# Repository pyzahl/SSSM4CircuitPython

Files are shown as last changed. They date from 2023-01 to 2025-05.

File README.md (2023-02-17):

# SSSM4CircuitPython
Solar Scintillation Seeing Monitor (SSSM) for CircuitPython

A renewed verion of a SSSM for CircuitPython on a ESP32-S2 or -S3-TFT.

Project based on hardware described here
https://www.blackwaterskies.co.uk/2017/06/diy-solar-scintillation-seeing-monitor-sssm/
or originally here:
https://vdocuments.mx/an-inexpensive-solar-scintillation-seeing-monitor-circuit-an-inexpensive.html

Let me copy the intro to SSSM:

A guide to building an inexpensive Solar Scintillation Seeing Monitor. The SSSM is a handy device which monitors the atmospheric seeing conditions during solar imaging. This SSSM can be built for a fraction of the cost of commercially available devices. You can use the SSSM to monitor seeing conditions through the day, or even to control your camera to capture images during the best seeing conditions.

Background:
The original design for the SSSM was published by E. J. Seykora at the Department of Physics, East Carolina University.

Read also how to integrate with Firecapture:
http://www.firecapture.de/
http://www.joachim-stehle.de/downloads/SSSMon/SSSMonPluginManual.pdf

Adapted schematics, connected to A0 and A1 for the ESP32-S2/S3-TFT replacing the originally used arduino.

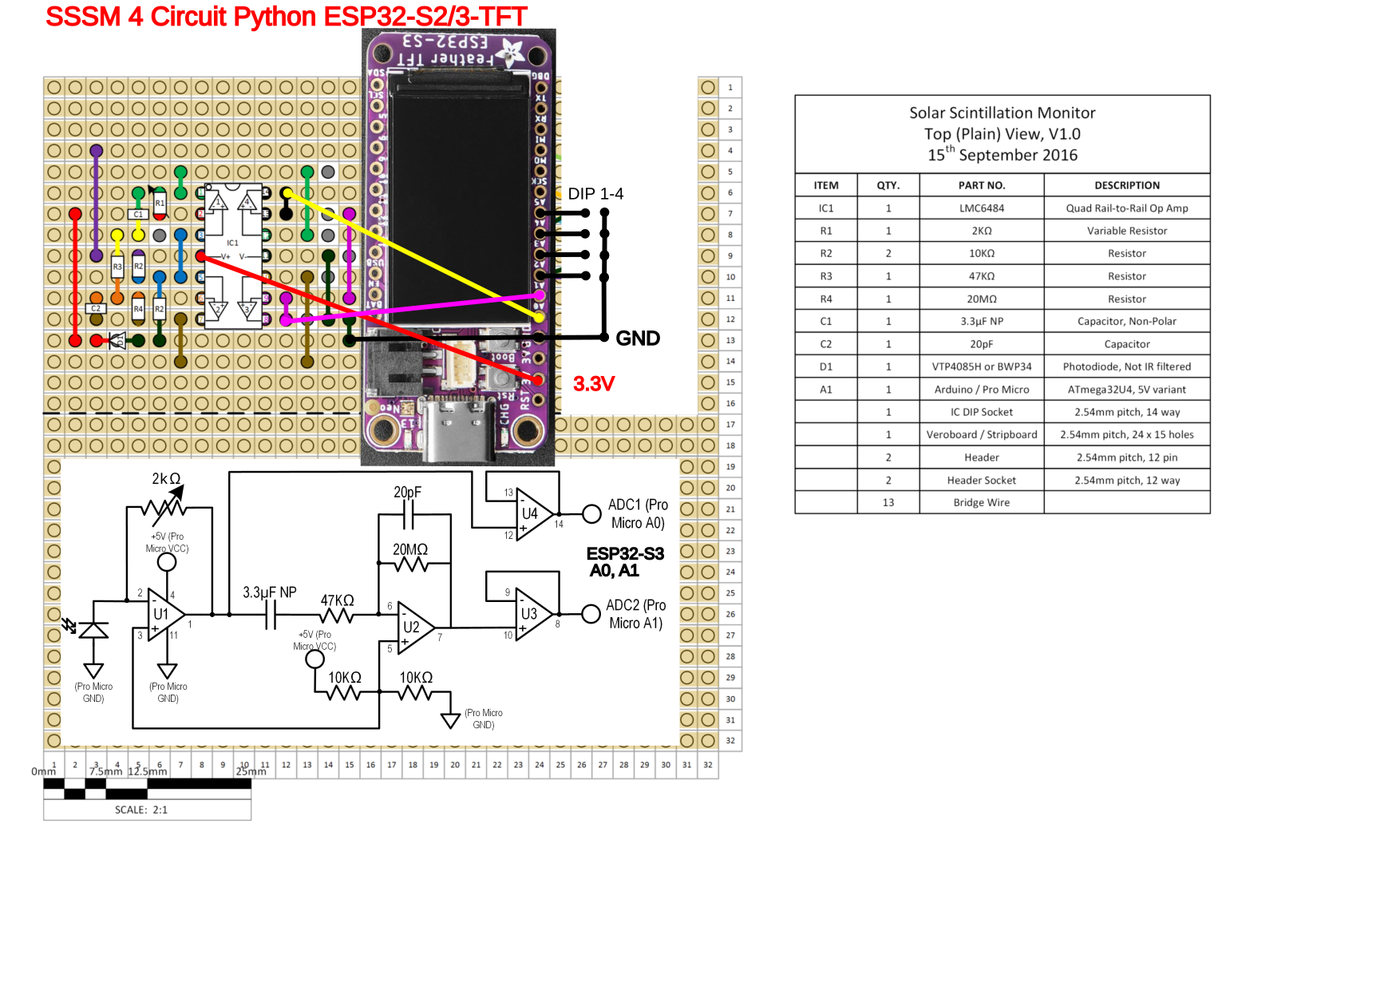
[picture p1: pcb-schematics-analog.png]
Schematics Analog circuit schematics and parts list for SSSM analog electronics


This project is based on CircuitPython Version 8 (all required Libs included for reference) running on a Adafruit ESP32-S2/S3-TFT. The S3 is faster and better suited.

Anyhwo, the new S3 seams to have issues with WiFi. WiFi is not required here in USB-Serial mode compatible with the original Firecapture SSSM plugin and interface. Anyways planns are to use for MQTT for web based publishing, this works with the ESP32-S2-TFT, even not long term stable. Causes "Wifi-OFF" Progra mhold on the S3. TDB. May be next gen/version of Circuit Python fixes it. 

Currently: CircuitPython 8.0.0-beta.6

https://circuitpython.org/board/adafruit_feather_esp32s3_tft/

Adafruit ESP32-S3 TFT Feather - 4MB Flash, 2MB PSRAM, STEMMA QT:

https://www.adafruit.com/product/5483
https://github.com/adafruit/Adafruit-ESP32-S3-TFT-Feather-PCB

Pinouts:

https://learn.adafruit.com/assets/114106

Optional support for digital LUX light sensor TSL2591: Lux and Mag reading.

Read the python code.py for details ;)

1) virtual zero volt calibration (about 3.3V/2 = 0V what is apporx a reading mapped to 32768. Exact dark values can be determined in "Zero Calibration Mode". And adjusted in the code.py in the top part lines 42,43.

```
#### original build V0
Analog0InCenter   = 32603
Analog1InCenter   = 32643
```

2) Operation Modes selectable via DIP Switch in my buid on pins A2,A3,A4,A5 -- open or closed to GND.

Alternatively the modes may be set via code overide liek this:
```
# DIP SWITCH INFO
print ('Note: DIP ON (=GND) := False')
for pin in sorted(DipSW):
	DipSW[pin].switch_to_input(pull=Pull.UP)

# override or set DIP wo dip sw in place:
#DipSW['2'].switch_to_input(pull=Pull.DOWN)
DipSW['3'].switch_to_input(pull=Pull.DOWN)
```

DIP Switch Assignments are:
```
## Operation Modes
DipSW = {
	'1': DigitalInOut(board.A2),  ## Read/Write (DIP on := GND [==Logic False]) => recording to logfile / no recording
	'2': DigitalInOut(board.A3),  ## WiFi+MQTT Logging On/Off  *** disabled Use I2C Sensor
	'3': DigitalInOut(board.A4),  ## FireCapture prints/Full report prints to console
	'4': DigitalInOut(board.A5),  ## Zero Calib Info ON / OFF
	}

DipSWinfoClosed = { ## Logic "False" as DIP=ON is pin on GND
        '1': 'Record to Logfile',
        '2': 'WiFi+MQTT IoT Transmit',
        '3': 'FC Print',
        '4': 'Zero Offset Calibration',
        }

DipSWinfoOpen = { ## Logic "True" = OPEN/OFF
        '1': 'No Logging',
        '2': 'No Wifi+MQTT',
        '3': 'Long Status Print',
        '4': 'Normal Operation',
        }
```

When hooked up to USB Serial (ttyACM0,..) terminal (CuteCom, screen,... or similar):

```
--- STARTUP ---

Auto-reload is on. Simply save files over USB to run them or enter REPL to disable.
code.py output:
<0x1b>]0;<0xf0><0x9f><0x90><0x8d>Wi-Fi: off | code.py | 8.0.0-beta.6<0x1b>\<0x1b>]0;<0xf0><0x9f><0x90><0x8d>Wi-Fi: No IP | code.py | 8.0.0-beta.6<0x1b>\Note: DIP ON (=GND) := False
Dip SW 1 Off: No Logging
Dip SW 2 Off: No Wifi+MQTT
Dip SW 3 On:  FC Mode
Dip SW 4 Off: Normal Operation
I2C addresses found: ['0xb']
Battery Percent: 100.00 %
Battery Voltage: 4.18 V
WiFi OFF, no NTP auto time set.
System Start Timestamp: 2000 01 01  01:15:23
MQTT disabled.
Checking for LUX sensor TSL2591
No I2C device at address: 0x29
... none
***
Zero Cal Init: [I, R, U0, U1]    20   19 1662 1662 mV  403.4  369.5 33007.3 33012.9
Zero Offset Calibration Warning! Please check dark.
***
Actual Center:  33007  33013
Actual Center:  33007  32998
Actual Center:  33008  33011
Actual Center:  33004  33008
***
I2C addresses found: ['0xb']
A0: 0.02
A1: 9.99
D0: 10.00
C2: 0.40
A0: 0.02
A1: 9.99
D0: 10.00
C2: 0.81
A0: 0.02
A1: 9.99
D0: 10.00
C2: 1.22
A0: 0.02
A1: 9.99
```

```
Wi-Fi: off | code.py | 8.0.0-beta.6
Wi-Fi: No IP | code.py | 8.0.0-beta.6
Note: DIP ON (=GND) := False
Dip SW 1 True No Logfile
Dip SW 2 False MQTT IoT Transmit
Dip SW 3 False FC Print
Dip SW 4 False WiFi
Battery Percent: 57.40 %
Battery Voltage: 3.87 V
Connecting WiFi...
Connecting to 31A138_5G
try: NTP clock sync...
try: Sync system time to NTP...
Start Timestamp: 2023 01 13  06:51:27
MQTT Client Configuration:
MQTT: Attempting to connect to 192.168.0.20::1883
Connected to MQTT Broker!
Flags: 0
 RC: 0
Checking for LUX sensor TSL2591
No I2C device at address: 0x29
... none
A0: 1.01
A1: 0.27
C2: 0.03
MQTT publishing...
A0: 1.01
A1: 0.25
C2: 0.05
MQTT publishing...
A0: 1.01
A1: 0.26
C2: 0.08
MQTT publishing...
A0: 1.01
A1: 0.27
C2: 0.10
MQTT publishing...
A0: 1.01
A1: 0.27
C2: 0.13
MQTT publishing...
A0: 1.01
A1: 0.27
C2: 0.16
```

```
Note: DIP ON (=GND) := False
Dip SW 1 Off: No Logging
Dip SW 2 On:  WiFi+MQTT IoT Transmit
Dip SW 3 On:  FC Print
Dip SW 4 Off: Normal Operation
I2C addresses found: ['0xb']
Battery Percent: 1.40 %
Battery Voltage: 3.95 V
Connecting WiFi...
Connecting to 31A138_5G
Connected to 31A138_5G!
try: NTP clock sync...
try: Sync system time to NTP...
Start Timestamp: 2023 01 31  08:54:03
MQTT Client Configuration:
MQTT: Attempting to connect to 192.168.0.20::1883
Connected to MQTT Broker!
Flags: 0
 RC: 0
Checking for LUX sensor TSL2591
No I2C device at address: 0x29
... none
***
Zero Cal Init: [I, R, U0, U1]  -1602 -1604   40   39 mV -31814.8 -31859.6  788.2  770.0
Zero Offset Calibration Warning! Please check dark.
***
Actual Center:    788    770

*** WiFi issue here...
Wi-Fi: off | Done | 8.0.0-beta.6
Auto-reload is off.
```

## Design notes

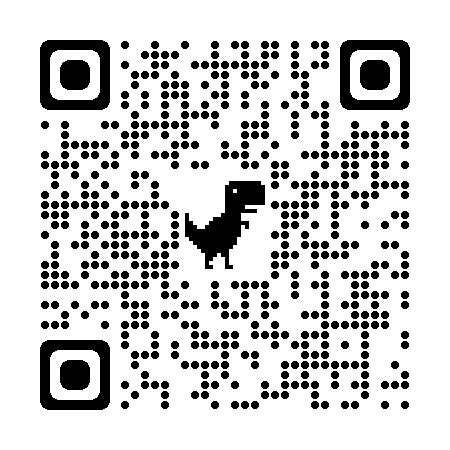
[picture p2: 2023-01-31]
qr.jpeg

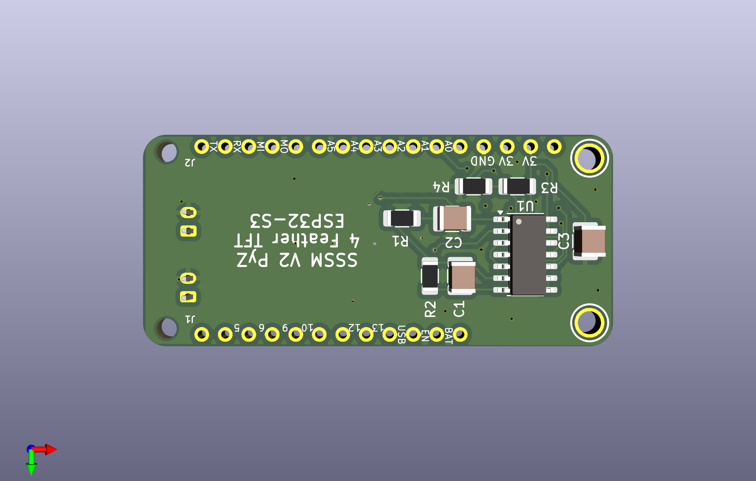
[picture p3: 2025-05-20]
CAD/ESP32-S3-TFT-bot.png

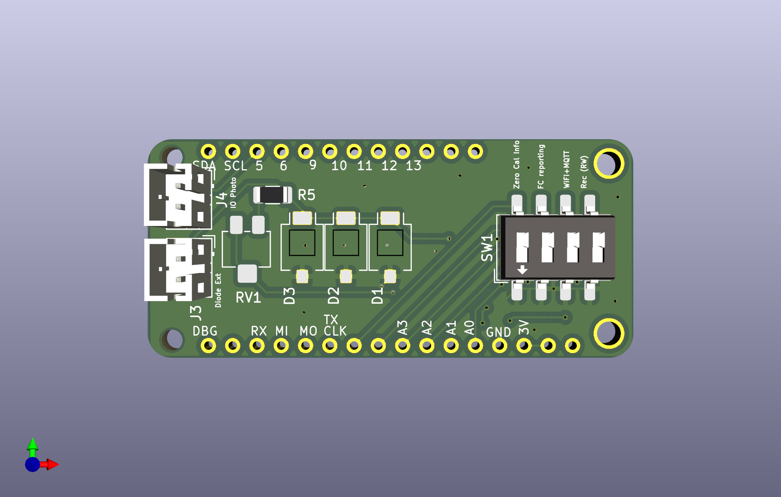
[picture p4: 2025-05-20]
CAD/ESP32-S3-TFT-top.png

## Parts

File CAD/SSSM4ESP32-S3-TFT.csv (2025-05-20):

Reference | Value | Footprint | Datasheet | Qty | DNP | Exclude from BOM | Exclude from Board
C1 | 20p | Capacitor_SMD:C_1210_3225Metric | ~ | 1
C2 | 3u3 | Capacitor_SMD:C_1210_3225Metric | ~ | 1
C3 | 100n | Capacitor_SMD:C_1210_3225Metric | ~ | 1
D1,D2,D3 | BPW34-SMD | OptoDevice:Osram_BPW34S-SMD | https://dammedia.osram.info/media/resource/hires/osram-dam-5488319/BPW%2034%20S_EN.pdf | 3
J1 | Conn_01x12_Socket |  | ~ | 1
J2 | Conn_01x16_Socket |  | ~ | 1
J3,J4 | Conn_01x02_Pin | Connector_JST:JST_PH_B2B-PH-K_1x02_P2.00mm_Vertical | ~ | 2
R1 | 47k | Resistor_SMD:R_1206_3216Metric | ~ | 1
R2 | 20M | Resistor_SMD:R_1206_3216Metric | ~ | 1
R3,R4 | 10k | Resistor_SMD:R_1206_3216Metric | ~ | 2
R5 | 0 | Resistor_SMD:R_1206_3216Metric | ~ | 1
RV1 | 2k | Potentiometer_SMD:Potentiometer_Bourns_3224X_Vertical | ~ | 1
SW1 | SW_DIP_x04 | Button_Switch_SMD:SW_DIP_SPSTx04_Slide_6.7x11.72mm_W8.61mm_P2.54mm_LowProfile | ~ | 1
U1 | LMC6484 | Package_SO:SOIC-14_3.9x8.7mm_P1.27mm | http://www.ti.com/lit/ds/symlink/lmc6484.pdf | 1

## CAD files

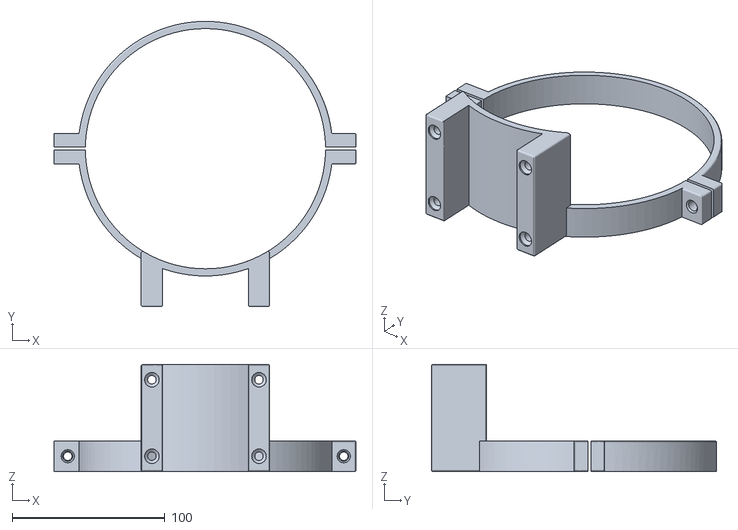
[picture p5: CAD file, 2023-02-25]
case_3d_print/SSSM-Feather-ESP32-S3-TFT-box-bracket-157-new.stl
197.4 x 186.4 x 70.0

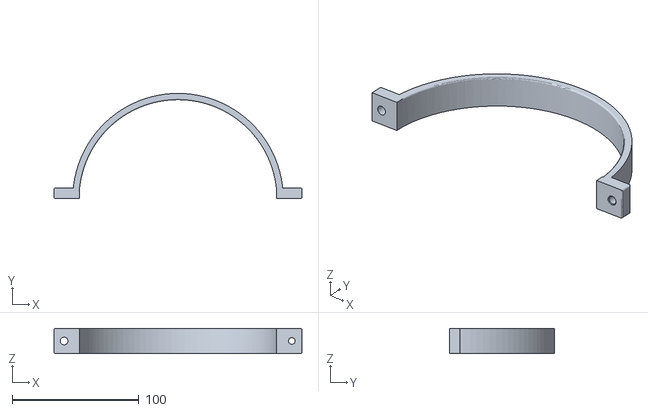
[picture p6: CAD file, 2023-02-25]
case_3d_print/SSSM-Feather-ESP32-S3-TFT-box-bracket-156.stl
196.0 x 83.2 x 20.0

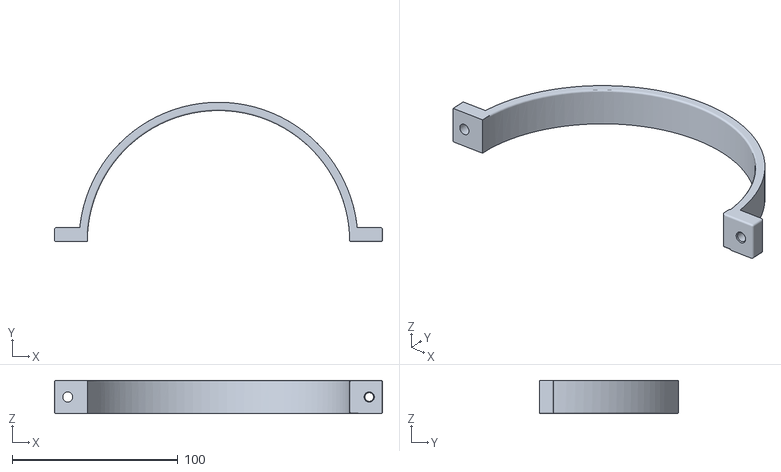
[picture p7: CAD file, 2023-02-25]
case_3d_print/SSSM-Feather-ESP32-S3-TFT-box-bracket-158.stl
198.0 x 84.2 x 20.0

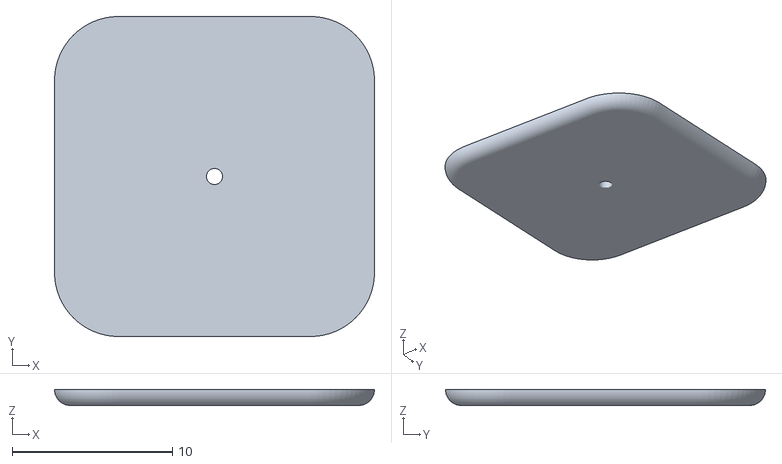
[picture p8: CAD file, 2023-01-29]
case_3d_print/SSSM-Feather-ESP32-S3-TFT-box-Ap00-WH.stl
20.0 x 20.0 x 1.00

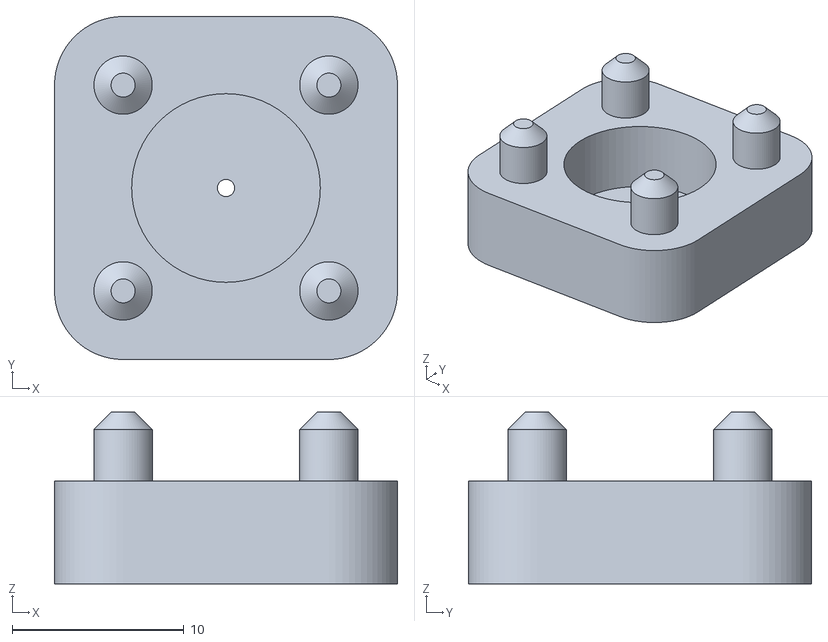
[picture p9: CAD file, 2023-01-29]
case_3d_print/SSSM-Feather-ESP32-S3-TFT-box-Ap00-BLK.stl
20.0 x 20.0 x 10.0

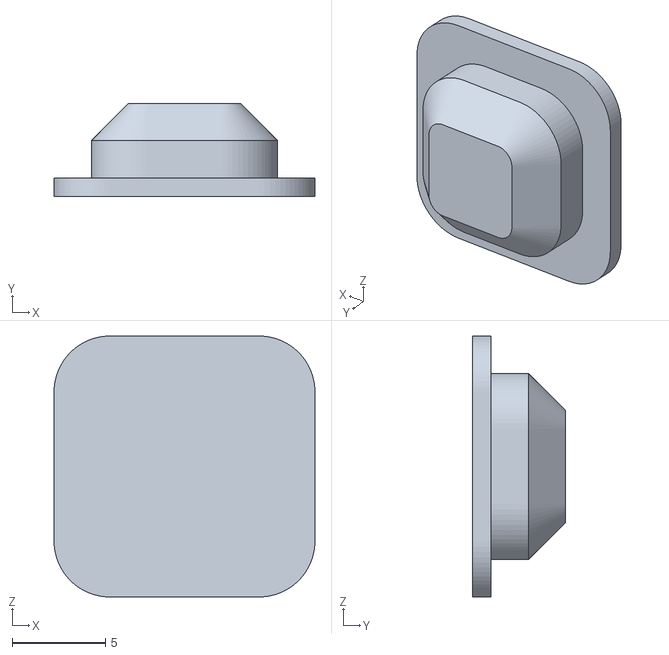
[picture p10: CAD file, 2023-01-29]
case_3d_print/SSSM-Feather-ESP32-S3-TFT-box-SW-Lid-BLK.stl
14.0 x 5.00 x 14.0

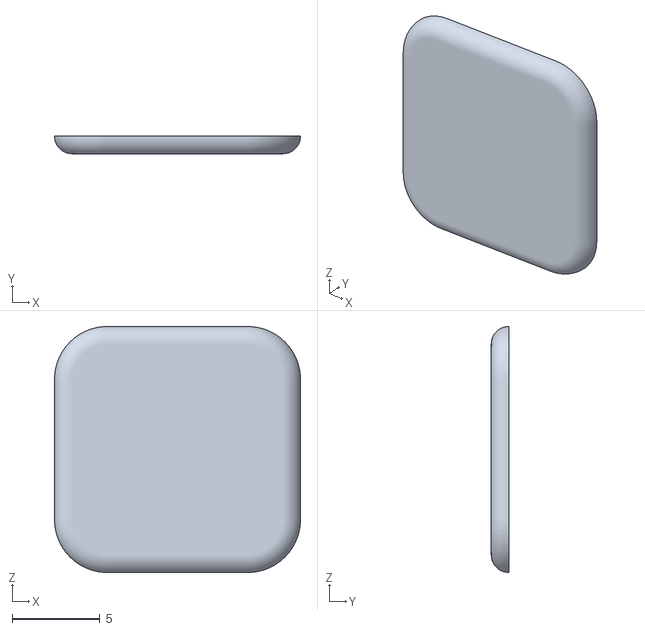
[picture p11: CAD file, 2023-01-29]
case_3d_print/SSSM-Feather-ESP32-S3-TFT-box-SW-Lid-WH.stl
14.0 x 1.00 x 14.0

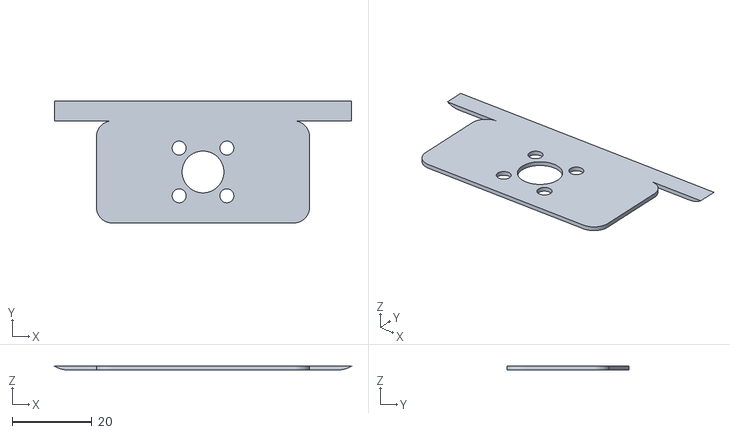
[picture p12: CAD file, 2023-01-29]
case_3d_print/SSSM-Feather-ESP32-S3-TFT-box-pilot-hole-wlid-WH.stl
74.6 x 30.7 x 1.00

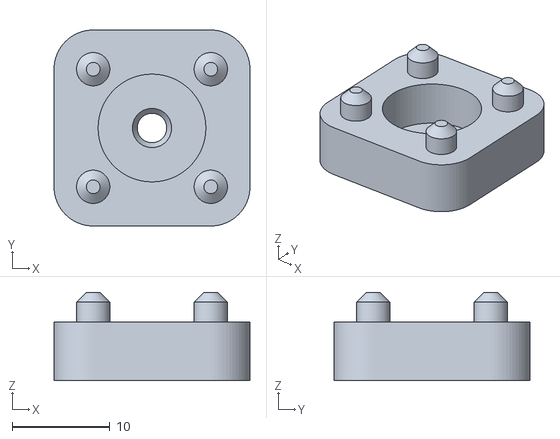
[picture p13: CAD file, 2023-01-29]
case_3d_print/SSSM-Feather-ESP32-S3-TFT-box-Ap2mm-BLK.stl
20.0 x 20.0 x 9.00

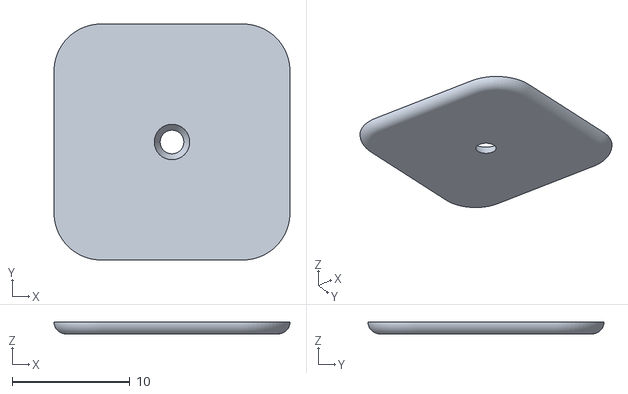
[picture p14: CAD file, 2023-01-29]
case_3d_print/SSSM-Feather-ESP32-S3-TFT-box-Ap2mm-WH.stl
20.0 x 20.0 x 1.00

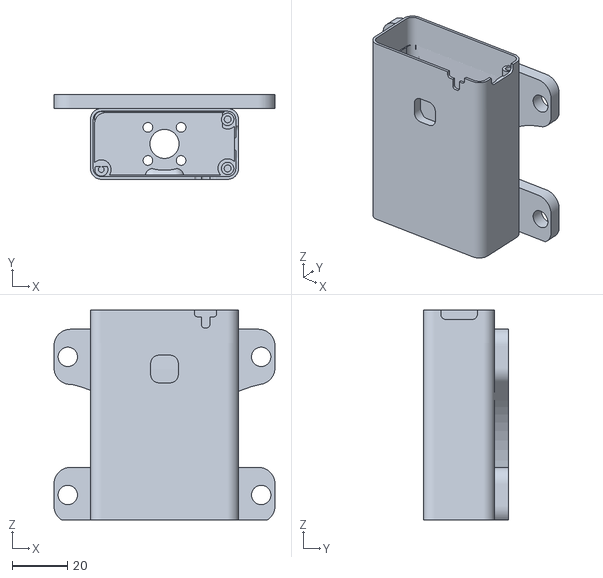
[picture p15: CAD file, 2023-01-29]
case_3d_print/SSSM-Feather-ESP32-S3-TFT-box-w-hole-BKL.stl
80.0 x 30.7 x 75.9

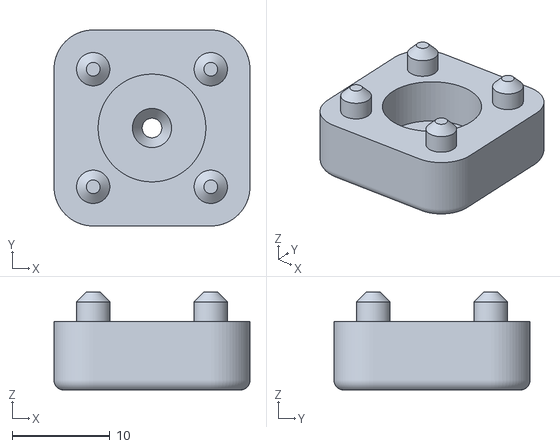
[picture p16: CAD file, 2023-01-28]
case_3d_print/SSSM-Feather-ESP32-S3-TFT-box-Ap3mm-dual.stl
20.0 x 20.0 x 10.0

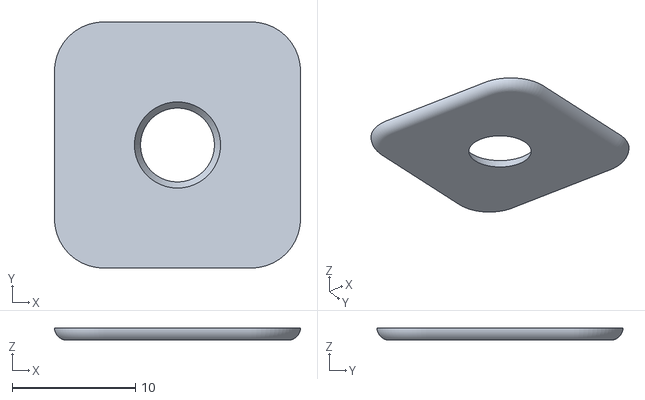
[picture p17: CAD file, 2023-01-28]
case_3d_print/SSSM-Feather-ESP32-S3-TFT-box-Ap6mm-dualWH.stl
20.0 x 20.0 x 1.00

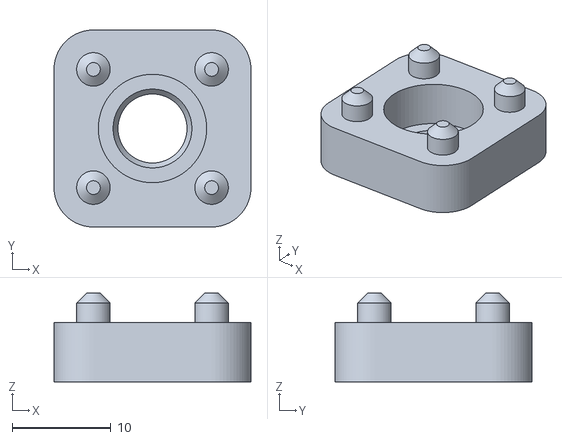
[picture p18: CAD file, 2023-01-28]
case_3d_print/SSSM-Feather-ESP32-S3-TFT-box-Ap6mm-dualBLK.stl
20.0 x 20.0 x 9.00

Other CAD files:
case_3d_print/SSSM-Feather-ESP32-S3-TFT-box-w-hole-WH.stl
case_3d_print/SSSM-Feather-ESP32-S3-TFT-box-Ap00-dual.stl
case_3d_print/SSSM-Feather-ESP32-S3-TFT-box.stp
case_3d_print/SSSM-Feather-ESP32-S3-TFT-box-w-hole.stl
case_3d_print/Feather TFT.step
case_3d_print/SSSM-Feather-ESP32-S3-TFT-box-A.stl
case_3d_print/SSSM-Feather-ESP32-S3-TFT-box-A.stp
case_3d_print/SSSM-Feather-ESP32-S3-TFT-box-Ap00.stl
case_3d_print/SSSM-Feather-ESP32-S3-TFT-box-Ap2mm.stl
case_3d_print/SSSM-Feather-ESP32-S3-TFT-box-Ap3mm.stl
case_3d_print/SSSM-Feather-ESP32-S3-TFT-box-Ap6mm.stl
case_3d_print/SSSM-Feather-ESP32-S3-TFT-box-B.stl
case_3d_print/SSSM-Feather-ESP32-S3-TFT-box-B.stp
case_3d_print/SSSM-Feather-ESP32-S3-TFT-box-SW-Lid.stl
case_3d_print/SSSM-Feather-ESP32-S3-TFT-box-hole4pot.stp
case_3d_print/SSSM-Feather-ESP32-S3-TFT-box.stl

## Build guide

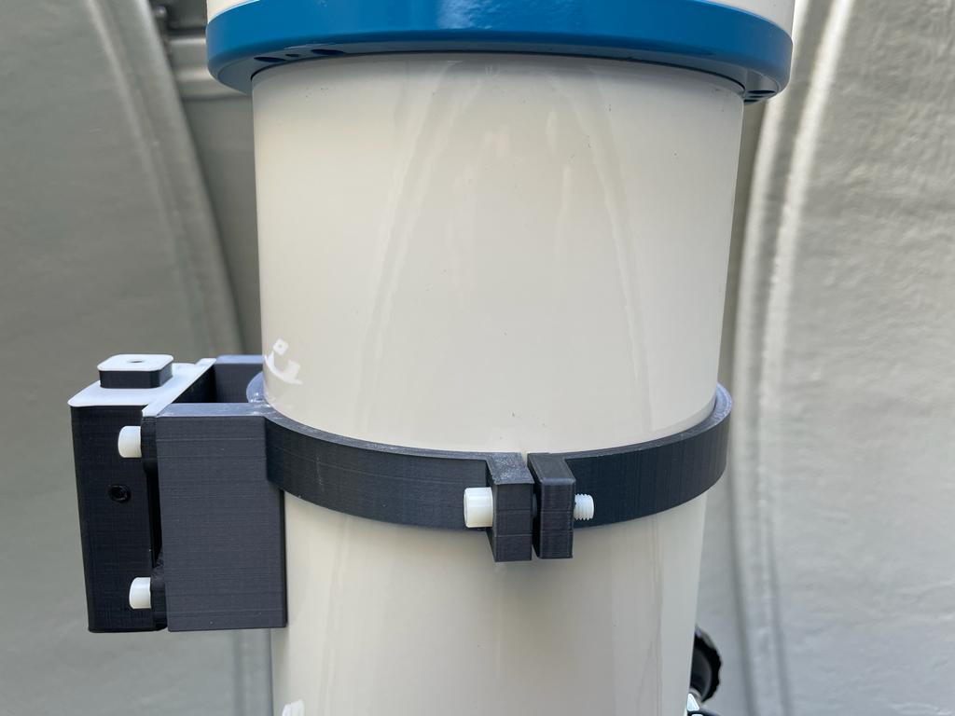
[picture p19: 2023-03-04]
case_3d_print/SSSM-Feather-ESP32-S3-TFT-box-complete-photo.jpeg

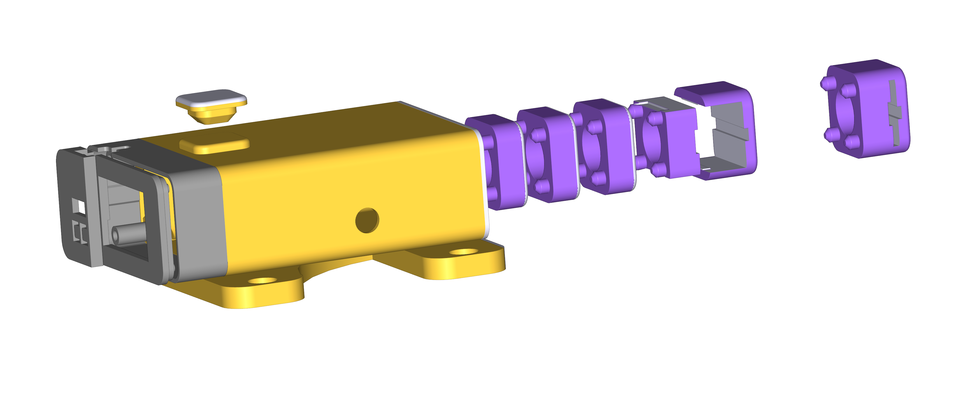
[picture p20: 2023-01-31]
case_3d_print/SSSM-Feather-ESP32-S3-TFT-box-hole4pot-dual.png

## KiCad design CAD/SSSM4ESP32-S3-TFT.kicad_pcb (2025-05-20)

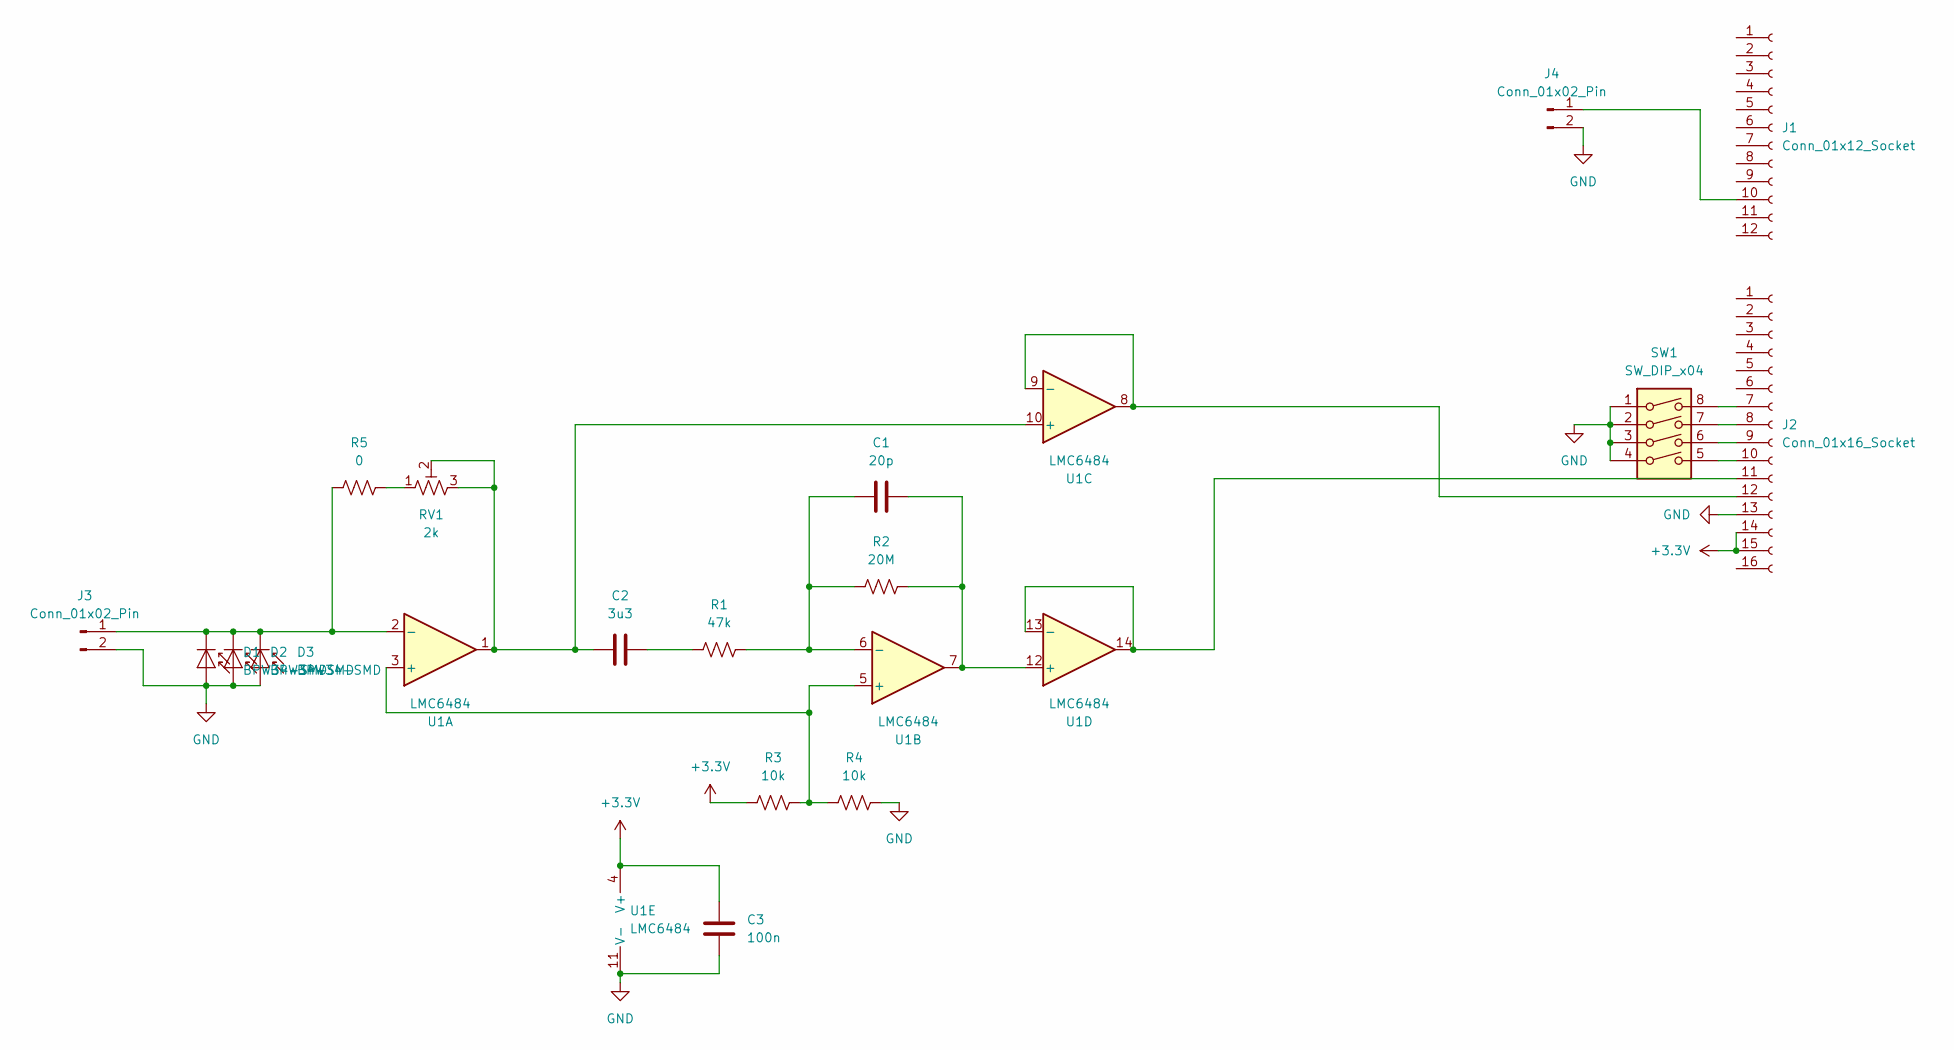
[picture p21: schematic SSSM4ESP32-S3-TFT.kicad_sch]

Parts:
C1: 20p; C_1210_3225Metric
C2: 3u3; C_1210_3225Metric
C3: 100n; C_1210_3225Metric
D1, D2, D3: BPW34-SMD; Osram_BPW34S-SMD
J1: Conn_01x12_Socket
J2: Conn_01x16_Socket
J3, J4: Conn_01x02_Pin; JST_PH_B2B-PH-K_1x02_P2.00mm_Vertical
R1: 47k; R_1206_3216Metric
R2: 20M; R_1206_3216Metric
R3, R4: 10k; R_1206_3216Metric
R5: 0; R_1206_3216Metric
RV1: 2k; Potentiometer_Bourns_3224X_Vertical
SW1: SW_DIP_x04; SW_DIP_SPSTx04_Slide_6.7x11.72mm_W8.61mm_P2.54mm_LowProfile
U1: LMC6484; SOIC-14_3.9x8.7mm_P1.27mm

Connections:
+3.3V: C3.2, J2.14, J2.15, R3.1, U1.4 (V+)
GND: C3.1, D1.2 (A), D2.2 (A), D3.2 (A), J2.13, J3.2, J4.2, R4.2, SW1.1, SW1.2, SW1.3, SW1.4, U1.11 (V-)
unnamed: C2.2, R1.1
unnamed: D1.1 (K), D2.1 (K), D3.1 (K), J3.1, R5.1, U1.2 (-)
unnamed: J1.10, J4.1
unnamed: J2.7, SW1.8
unnamed: J2.8, SW1.7
unnamed: J2.9, SW1.6
unnamed: J2.10, SW1.5
unnamed: J2.11, U1.13 (-), U1.14
unnamed: J2.12, U1.8, U1.9 (-)
unnamed: R5.2, RV1.1
unnamed: R3.2, R4.1, U1.3 (+), U1.5 (+)
unnamed: C1.1, R1.2, R2.1, U1.6 (-)
unnamed: C2.1, RV1.2, RV1.3, U1.1, U1.10 (+)
unnamed: C1.2, R2.2, U1.7, U1.12 (+)

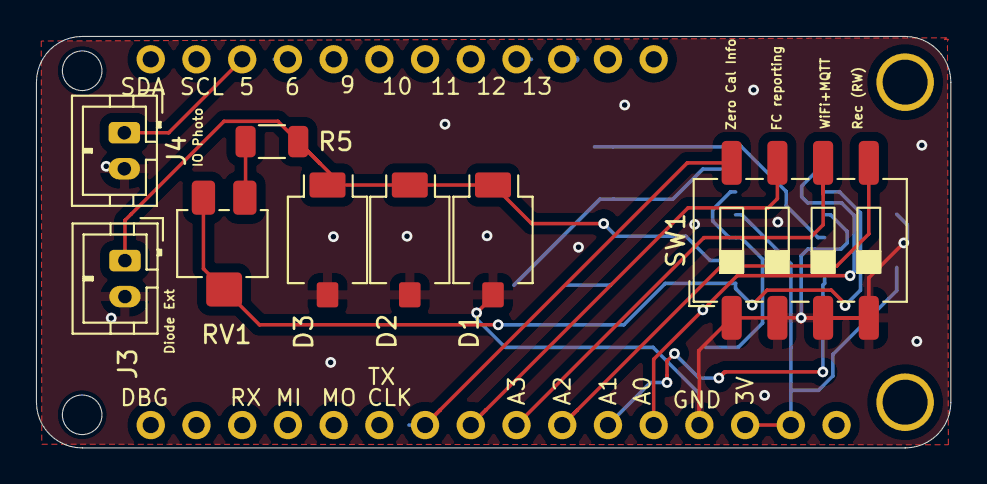
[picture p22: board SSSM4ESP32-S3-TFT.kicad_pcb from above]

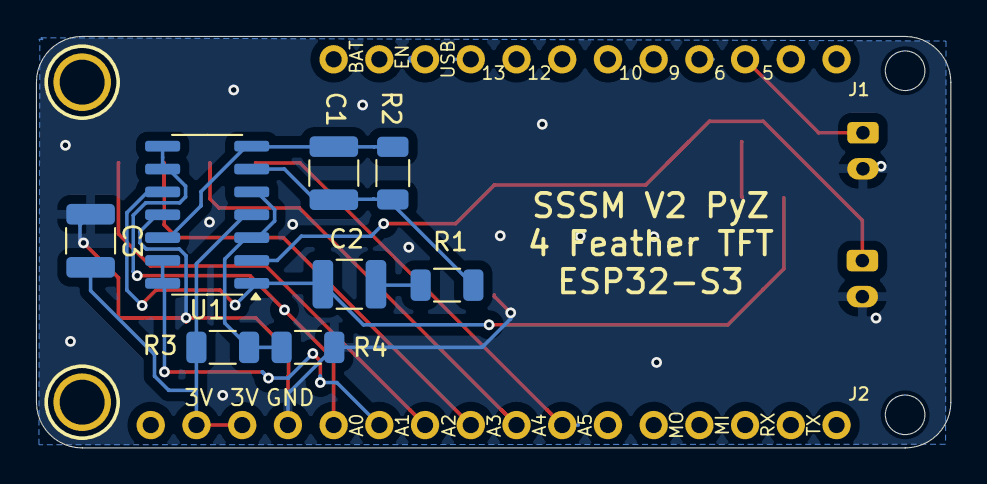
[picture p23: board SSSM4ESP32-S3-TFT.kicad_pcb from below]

Board: 2 copper layers, 50.8 x 22.9 mm, 22 parts (12 on the bottom side), 16 nets.

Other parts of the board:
U$31, U$32: MOUNTINGHOLE2.5; MOUNTINGHOLE_2.5_PLATED
UNK_HOLE_0: dummyfp0
UNK_HOLE_1: dummyfp1

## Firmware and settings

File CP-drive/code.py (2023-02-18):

# SSSM for Feather Adafruit ESP32 S2/S3 TFT
# Welcome to CircuitPython 8 :)
# (C) PyZahl 2023

import board
import gc
import time
import math
from digitalio import DigitalInOut, Direction, Pull
from analogio import AnalogIn
#from audioio import WaveFile, AudioOut
#import touchio
#import pulseio
import displayio
#from adafruit_st7789 import ST7789
from adafruit_display_shapes.rect import Rect

import busio
import ipaddress
from adafruit_lc709203f import LC709203F, PackSize

import ssl
import socketpool
import wifi
import adafruit_ntp
import rtc
import adafruit_minimqtt.adafruit_minimqtt as MQTT
import adafruit_requests

import random
#from rainbowio import colorwheel
from adafruit_esp32s2tft import ESP32S2TFT

## Setup the machine

gc.collect()   # make some rooooom

##                          S2 new S2 old
#             Center Value  CZ     Py      Ideal
R2_N_Measurements = 43 ## sqrt (N Samples for Ref Int and RMS)
##
#### new build V1
Analog0InCenter   = 33028
Analog1InCenter   = 33029
## 55  Zero Cal Info: [I, R, U0, U1]  21.58  20.30 1662.75 1663.12 mV avI,R:  436.3  405.0 avU0,1: 33027.8 33028.8 U0,1: 33021.2 33028.6 ## new build CZ - ESP32-S3

## Operation Modes
DipSW = {
	'1': DigitalInOut(board.A2),  ## Read/Write (DIP on := GND [==Logic False]) => recording to logfile / no recording
	'2': DigitalInOut(board.A3),  ## WiFi+MQTT Logging On/Off  *** disabled Use I2C Sensor
	'3': DigitalInOut(board.A4),  ## FireCapture prints/Full report prints to console
	'4': DigitalInOut(board.A5),  ## Zero Calib Info ON / OFF
	}

DipSWinfoClosed = { ## Logic "False" as DIP=ON is pin on GND
        '1': 'Record to Logfile',
        '2': 'WiFi+MQTT IoT Transmit',
        '3': 'FC Print',
        '4': 'Zero Offset Calibration',
        }

DipSWinfoOpen = { ## Logic "True" = OPEN/OFF
        '1': 'No Logging',
        '2': 'No Wifi+MQTT',
        '3': 'Long Status Print',
        '4': 'Normal Operation',
        }

## Print DIP SWITCH INFO
print ('Note: DIP ON (=GND) := False')
for pin in sorted(DipSW):
    DipSW[pin].switch_to_input(pull=Pull.UP)
    if DipSW[pin].value == False:
            info = DipSWinfoClosed[pin]
            dip='On: '
    else:
            info = DipSWinfoOpen[pin]
            dip='Off:'
    print ('Dip SW', pin, dip, info)

## Set a GPIO pin for digital Photo OK
## Photo OK threashold:
PhotoOKArcs = 1.0
PinPhotoOK = DigitalInOut(board.D5)
PinPhotoOK.direction = Direction.OUTPUT

## S3 dual core required wait patch/hack -- I2C issue with current batter monitor driver
def wait_i2c_ready():
	i2c = board.I2C()
	while not i2c.try_lock():
	    pass
	running = True
	try:
	    while running:
		print(
		    "I2C addresses found:",
		    [hex(device_address) for device_address in i2c.scan()],
		)
		# time.sleep(2)
		running = False

	finally:  # unlock the i2c bus when ctrl-c'ing out of the loop
	    i2c.unlock()
## S3 dual core required patch

## Configure Battery Monitor
# Create sensor object, using the board's default I2C bus.
wait_i2c_ready()
battery_monitor = LC709203F(board.I2C())

# Update to match the mAh of your battery for more accurate readings.
# Can be MAH100, MAH200, MAH400, MAH500, MAH1000, MAH2000, MAH3000.
# Choose the closest match. Include "PackSize." before it, as shown.
battery_monitor.pack_size = PackSize.MAH1000 #MAH400   # MAH1200 ???

bm_cell_percent=battery_monitor.cell_percent
print("Battery Percent: {:.2f} %".format(bm_cell_percent))
print("Battery Voltage: {:.2f} V".format(battery_monitor.cell_voltage))
    
 
# Get wifi credentials and details and more credentials (MQTT) from a secrets.py file
try:
    WiFi = True
    from secrets import secrets
except ImportError:
    print("WiFi secrets are kept in secrets.py, please add them there!")
    print("WiFi off now.")
    WiFi = False # disable to continue
    raise

if WiFi and DipSW['2'].value == False:
        print('Connecting WiFi...')
        print("Connecting to %s" % secrets["ssid"])
        wifi.radio.connect(secrets["ssid"], secrets["password"])
        print("Connected to %s!" % secrets["ssid"])

        pool = socketpool.SocketPool(wifi.radio)
        ntp = adafruit_ntp.NTP(pool, tz_offset=5)

        print('try: NTP clock sync...')

        #print(ntp.datetime)
        #print(time.localtime())

        # NOTE: This changes the system time so make sure you aren't assuming that time
        print('try: Sync system time to NTP...')
        rtc.RTC().datetime = ntp.datetime
        tmnow = time.localtime()
        #struct_time(tm_year=2022, tm_mon=7, tm_mday=22, tm_hour=4, tm_min=56, tm_sec=28, tm_wday=4, tm_yday=203, tm_isdst=-1)
        print('Start Timestamp: {:04d} {:02d} {:02d}  {:02d}:{:02d}:{:02d}'.format(tmnow.tm_year, tmnow.tm_mon, tmnow.tm_mday, tmnow.tm_hour, tmnow.tm_min, tmnow.tm_sec))
        WiFi = True
else:
        print ('WiFi OFF, no NTP auto time set.')
        tmnow = time.localtime()
        print ('System Start Timestamp: {:04d} {:02d} {:02d}  {:02d}:{:02d}:{:02d}'.format(tmnow.tm_year, tmnow.tm_mon, tmnow.tm_mday, tmnow.tm_hour, tmnow.tm_min, tmnow.tm_sec))
        WiFi = False

## MQTT ##  
# Setup a feed named 'photocell' for publishing to a feed
sssm_time_feed = "feeds/sssm/time"
sssm_arcs_feed = "feeds/sssm/arcs"
sssm_ref_feed  = "feeds/sssm/refint"
sssm_bat_feed  = "feeds/sssm/battery"

## test adafruit.io -- very limited rate and points (30/min total)
#sssm_time_feed = "pyzahl2/feeds/sssm.time"
#sssm_arcs_feed = "pyzahl2/feeds/sssm.arcs"
#sssm_ref_feed  = "pyzahl2/feeds/sssm.refint"
#sssm_bat_feed  = "pyzahl2/feeds/sssm.battery"

# Setup a feed named 'onoff' for subscribing to changes
#onoff_feed = "/feeds/info"

## MQTT support callbacks
def connect(mqtt_client, userdata, flags, rc):
    print("Connected to MQTT Broker!")
    print("Flags: {0}\n RC: {1}".format(flags, rc))


def disconnect(mqtt_client, userdata, rc):
    print("Disconnected from MQTT Broker!")


def subscribe(mqtt_client, userdata, topic, granted_qos):
    print("Subscribed to {0} with QOS level {1}".format(topic, granted_qos))


def unsubscribe(mqtt_client, userdata, topic, pid):
    print("Unsubscribed from {0} with PID {1}".format(topic, pid))


def publish(mqtt_client, userdata, topic, pid):
    print("Published to {0} with PID {1}".format(topic, pid))


def message(client, topic, message):
    print("New message on topic {0}: {1}".format(topic, message))

## Initiate MQTT
if WiFi:
        print ('MQTT Client Configuration:')
        #pool = socketpool.SocketPool(wifi.radio) ## got that above already

        mqtt_client = MQTT.MQTT(
                broker=secrets["broker"],
                port=secrets["port"],
                username=secrets["aio_username"],
                password=secrets["aio_key"],
                socket_pool=pool,
                #is_ssl=True,
                #ssl_context=ssl.create_default_context(),
        )

        mqtt_client.on_connect = connect
        mqtt_client.on_disconnect = disconnect
        mqtt_client.on_subscribe = subscribe
        mqtt_client.on_unsubscribe = unsubscribe
        #mqtt_client.on_publish = publish
        mqtt_client.on_message = message

	print("MQTT: Attempting to connect to {}::{}".format(mqtt_client.broker, mqtt_client.port))
	try:
		mqtt_client.connect()
		mqtt_client_connected = True
	except RuntimeError as e:
		print ('Connect error: ',e)
		mqtt_client_connected = False
	        print ('MQTT disabled now.')
else:
        print ('MQTT disabled.')

## Create/append to logfile on drive?
## NOTE: Make sure to purge/delete manually when using too much space!!
logging = False
if DipSW['1'].value == False:
	try:
	    with open("/lightcurve.log", "a") as light_log:
		light_log.write('# Log Start: {:04d} {:02d} {:02d}  {:02d}:{:02d}:{:02d}'.format(tmnow.tm_year, tmnow.tm_mon, tmnow.tm_mday, tmnow.tm_hour, tmnow.tm_min, tmnow.tm_sec))
		light_log.flush()
		logging = True
	except OSError as e:  # When the filesystem is NOT writable by CircuitPython...
		print('Can not access drive:', e)

### Prepare data strcutures for graphics
### ESP32-S2 240MHz Color 1.14" IPS TFT with 240x135 pixels ST7789
esp32s2tft = ESP32S2TFT(
    default_bg=0x000000,
    scale=1,
)


# Create the labels
status = esp32s2tft.add_text(
	text='SSSM V1.0',
	text_position=(0, 10),
	text_scale=3,
	text_color=0xFF00FF
)

battery = esp32s2tft.add_text(
	text='{:.1f} %'.format(bm_cell_percent),
	text_position=(240, 10),
	text_anchor_point=(1.0, 0.5),
	text_scale=1,
	text_color=0x00FF00
)

info_last = " "
info_label = esp32s2tft.add_text(
	text=info_last,
	line_spacing=1.0,
	text_position=(240, 20),
	text_anchor_point=(1.0, 0.5),
	text_scale=1,
	text_color=0x606060,
)

reading_last = '(C) PyZahl'

reading = esp32s2tft.add_text(
	text=reading_last,
	text_position=(0, 40),
	text_scale=2,
	text_anchor_point=(0.0, 0.5),
	text_color=0xFFFF00,
)

if 1:
	reading_aux_last = 'Happy Seeing'
#	reading_aux_last = 'Happy Birthday'

	reading_aux = esp32s2tft.add_text(
		text=reading_aux_last,
		text_position=(0, 65),
		text_scale=2,
		text_anchor_point=(0.0, 0.5),
		text_color=0xFFFF00,
	)

	reading_arc_last = 'K150'
#	reading_arc_last = 'Carsten!!!'

	reading_arc = esp32s2tft.add_text(
		text=reading_arc_last,
		text_position=(0, 90),
		text_scale=2,
		text_anchor_point=(0.0, 0.5),
		text_color=0xFFFF00,
	)

# Prepare plotting area bitmap        
if 1:
	GYMAX = 70
	GYMAX1=GYMAX-1
	graph_bitmap = displayio.Bitmap(240, GYMAX, 6)
	color_palette = displayio.Palette(6)
	color_palette[0] = 0x000000 # clear, black
	color_palette[1] = 0xFF4000 # orange for arcs
	color_palette[2] = 0xFFFF00 # yellow for ref sun intensity 
	color_palette[3] = 0x0000FF # blue
	color_palette[4] = 0x330000 # dark red, grid
	color_palette[5] = 0x003300 # 1 arcs line / dark green

	gr_sprite = displayio.TileGrid(graph_bitmap,
		                       pixel_shader=color_palette,
		                       x=0, y=55)
		                       
	esp32s2tft.splash.append(gr_sprite)


#NN=32
#for i in range(NN):
#	esp32s2tft.splash.append(Rect(i*8, 100, 4, 20, fill=0x00FF00))

esp32s2tft.display.show(esp32s2tft.splash)

## Configure Analog Inputs used
# Analog input on A1
analog0in = AnalogIn(board.A0)   # Reference Intensity
analog1in = AnalogIn(board.A1)   # Analog integrated AC signal

######################### HELPERS ##############################

# Helper to convert analog input to voltage
def getVoltage(pin):
    return (pin.value * 3.3) / 65536

def Voltage(value):
    return (value * 3.3) / 65536

def mVoltage(value):
    return (value * 3.3) / 65.536

## Center/Zero Measurement
def SSSM_analog_zero_calib(n22=32):
	N=n22*n22
	fn22=float(n22)
        I=0
        R=0
        U0=0
        U1=0
        ## some integer math radix 2 tricks
	for i in range(N):
		u0 = analog0in.value - Analog0InCenter
		u1 = analog1in.value - Analog1InCenter
                I = I + u0
                R = R + u1
		U0 = U0 + analog0in.value
                U1 = U1 + analog1in.value
                ##**
        I=I/n22
        I=I/fn22
        R=R/n22
        R=R/fn22
        U0=U0/n22
        U0=U0/fn22
        U1=U1/n22
        U1=U1/fn22
        return I, R, U0, U1

        
## SSSM analog read -- NOTE: we do have only FLOAT here (30-bit wide floating point) and 32bit integer
def SSSM_analog(n22=32):
	I=0
	RMS=0
	N=n22*n22
	fn22=float(n22)
        ## some integer math radix 2 tricks
	for i in range(N):
		u0 = analog0in.value - Analog0InCenter
		u1 = analog1in.value - Analog1InCenter
		I = I + u0
		RMS= RMS + u1*u1

        ref = I/fn22   # I>>10 = I/32/32
	if ref < 1:
		ref = 1 # prevent div zero and negative nonsense

	rms = math.sqrt(RMS)  ## sqrt(RMS>>10) = sqrt(RMS)/32
	# arcs=1886.79/425.5*rms/ref ## 425.5 (=20M/47k) is the AC "400Hz" BW signal gain vs ref singal. 1886.79 is the conversion factor to arcs
	# 1886.79/425.5 = 4.434289
	# (rms / 32) / (ref / 32)
	arcs = 4.434289*rms/ref
	if arcs > 20: # clip
		arcs=20.0
                
	return ref/fn22, rms/fn22, arcs

## SSM test -- Only for testing, no actual use
def SSSM_test():
	nowns = time.monotonic_ns()
	startns = nowns
	while True:
		nowns = time.monotonic_ns()
		u0, u1, ref, rms, arcs = SSSM_analog()
		reading_last = 'A0 {:4.2f}V A1 {:4.2f}V'.format(Voltage(u0), Voltage(u1))
		reading_aux_last = 'I {:5.3f} RMS {:5.3f}'.format(Voltage(ref), Voltage(rms))
		reading_arc_last = 'ARCs {:5.2f}'.format(arcs)
		
		print (reading_last+', '+reading_aux_last)
		esp32s2tft.set_text(
			reading_last, reading
		)
		esp32s2tft.set_text(
			reading_aux_last, reading_aux
		)
		esp32s2tft.set_text(
			reading_arc_last, reading_arc
		)

		esp32s2tft.set_text(
			'{:.1f}s Bat {:.1f} %'.format((nowns-startns)/1e9, bm_cell_percent), battery
		)

#SSSM_test()


######################### MAIN LOOP ##############################

esp32s2tft.display.auto_refresh = False

#print('Test Log10(10): ', math.log(10)/2.302585092994046)

I0 = 0
i=0

klen = 16
kshr = 4
rmslen = 16
rmsshr = 4

ISum = -1
dI = 0
IrmsS = 0
arcs = 0.0

arcs_filter = 0.0
ref_filter = 0.0
rms_filter = 0.0

arcs_hist = []
refint_hist = []
nowns = time.monotonic_ns()
startns = nowns

##############
ZN=0
CAL_I, CAL_R, CAL_U0, CAL_U1 = SSSM_analog_zero_calib (R2_N_Measurements)
reading_last='{:4.0f} {:4.0f} {:4.0f} {:4.0f}'.format(mVoltage(CAL_I), mVoltage(CAL_R), mVoltage(CAL_U0), mVoltage(CAL_U1))
print ('***')
print ('Zero Cal Init: [I, R, U0, U1] ', reading_last, 'mV {:6.1f} {:6.1f} {:6.1f} {:6.1f}'.format(CAL_I, CAL_R, CAL_U0, CAL_U1))

if abs(mVoltage(CAL_I)) > 20 or abs(mVoltage(CAL_R)) > 20:
        print ('Zero Offset Calibration Warning! Please check dark.')
        print ('***')
        print ('Actual Center: {:6.0f} {:6.0f}'.format(CAL_U0, CAL_U1))
        CAL_I, CAL_R, CAL_U0, CAL_U1 = SSSM_analog_zero_calib (R2_N_Measurements)
        print ('Actual Center: {:6.0f} {:6.0f}'.format(CAL_U0, CAL_U1))
        CAL_I, CAL_R, CAL_U0, CAL_U1 = SSSM_analog_zero_calib (R2_N_Measurements)
        print ('Actual Center: {:6.0f} {:6.0f}'.format(CAL_U0, CAL_U1))
        CAL_I, CAL_R, CAL_U0, CAL_U1 = SSSM_analog_zero_calib (R2_N_Measurements)
        print ('Actual Center: {:6.0f} {:6.0f}'.format(CAL_U0, CAL_U1))
        print ('***')
else:
        print ('Zero Calibration: passed')
        print ('***')
#############

ref_filter, rms_filter, arcs_filter = SSSM_analog (R2_N_Measurements)

long_reading = '#SEC------\tRef--\tRMS--\tarcs--\tBAT%'
while True:
	# get time in seconds since start
	nowns = time.monotonic_ns()
	s=int((nowns-startns)/1e9)

	# take measurement (SSSM analog)
	ref, rms, arcs = SSSM_analog (R2_N_Measurements)

        # Calculate filtered values
        w  = 0.10 ## 10% IIR
        wf = 1.00-w
        ref_filter  = wf *  ref_filter + w * ref
        rms_filter  = wf *  rms_filter + w * rms
        arcs_filter = wf * arcs_filter + w * arcs
        #arcs_average10  = sum(arcs_hist[-10:])/10 # Average Seeing last 10 readings

        # intensity reference scaled:
        refint = ref/10 # just a value, linear here

        # record last values for plotting and statistics
	if len(arcs_hist) >= 240:
		arcs_hist.pop(0)
		refint_hist.pop(0)
		
	arcs_hist.append(arcs)
	refint_hist.append(refint)

        # Median once enough values
	if len(arcs_hist) >= 18:
            tmp = arcs_hist[-17:] # last 17
            tmp.sort()
            arcs_median = tmp[8]  # take middle value
        else:
            arcs_median = arcs_filter
        
	# log to file?	
	try:
	    with open("/lightcurve.log", "a") as light_log:
		light_log.write(long_reading+'\n')
		logging=True #print('Can not access drive:', e)
	except OSError as e:  # When the filesystem is NOT writable by CircuitPython...
		logging=False #print('Can not access drive:', e)

	# every 60s update battery info
        if s%60 == 0:
        	print('** Battery Check **')
	        wait_i2c_ready()
        	print('** reading...    **')
	        bm_cell_percent = battery_monitor.cell_percent
        	print('** Battery: {:.2f} %  {:.2f} V **'.format(bm_cell_percent, battery_monitor.cell_voltage))

	long_reading = '{:d}\t{:5.3f}\t{:6.3f}\t{:6.3f}\t{:5.1f}'.format(time.time(), Voltage(ref), Voltage(rms), arcs, bm_cell_percent)
        
        # Print Zero Cal Info
        if DipSW['4'].value == False:
                I, R, U0, U1 = SSSM_analog_zero_calib (R2_N_Measurements)
                CAL_I = CAL_I*0.99 + I*0.01
                CAL_R = CAL_R*0.99 + R*0.01
                CAL_U0 = CAL_U0*0.99 + U0*0.01
                CAL_U1 = CAL_U1*0.99 + U1*0.01
                ZN=ZN+1
	        reading_last='{:4.0f} {:4.0f} {:4.0f} {:4.0f}'.format(mVoltage(I), mVoltage(R), mVoltage(U0), mVoltage(U1))
                print (ZN,' Zero Cal Info: [I, R, U0, U1] {:6.2f} {:6.2f} {:6.2f} {:6.2f}'.format(mVoltage(I), mVoltage(R), mVoltage(U0), mVoltage(U1)), 'mV avI,R: {:6.1f} {:6.1f} avU0,1: {:6.1f} {:6.1f} U0,1: {:6.1f} {:6.1f}'.format(CAL_I, CAL_R, CAL_U0, CAL_U1, U0, U1))
        else:
        # DISPLAY Voltages Io, RMS or arcs_filter if "good"
                if arcs > 10 and ref > 2000:
	                reading_last='Io{:6.1f}mV S {:4.1f}"'.format(mVoltage(ref_filter), arcs_filter)
                else:
	                reading_last='Io{:6.1f}mV R {:4.1f}mV'.format(mVoltage(ref_filter), mVoltage(rms_filter))

	# Draw graph into bitmap
	x=0
	yp=0
	for yval in (arcs_hist):
		# clear column
		for yc in range(0,GYMAX):
			if yc % 10 == 0:	
				graph_bitmap[x, yc] = 4	# grid line
			else:
				graph_bitmap[x, yc] = 0	# clear
		graph_bitmap[x, GYMAX-10] = 5 # green (1 arcs grid line) 
		yi = GYMAX1 - int(round(yval*10))%GYMAX
                # draw arcs history graph
		while yp != yi:
			if yp > yi:
				yp = yp - 1
			else:
				yp = yp + 1
			graph_bitmap[x, yp] = 1
		if yp < GYMAX1:
			graph_bitmap[x, yp+1] = 1

                # draw ref intensity history graph -- auto scale (decades)
		yval = refint_hist[x]
		while yval > 10.:
			yval = yval/10.
		while yval < 1.:
			yval = yval*10.
		yi = GYMAX1 - int(round(yval/10.*GYMAX))
		graph_bitmap[x, yi%GYMAX] = 2
		if yi < GYMAX1:
			graph_bitmap[x, yi+1] = 2 #
		x=x+1

        # DISPLAY ARCS MAIN STATUS
	if arcs < 10.0 and ref > 2000: # ref voltage > 200mV
		status_reading = 'S {:4.1f}"'.format(arcs_median)
	else:
		arcs = 9.99
		status_reading = 'SSSM *"'

	esp32s2tft.set_text(
		status_reading, status
	)

	esp32s2tft.set_text(
		reading_last, reading
	)

	esp32s2tft.set_text(
		info_last, info_label
	)

	esp32s2tft.set_text(
		'{:.1f}s Bat {:.1f} %'.format(s, bm_cell_percent), battery
	)

	esp32s2tft.set_text_color(
		0xFF0000 if bm_cell_percent < 20 else 0x00FF00, battery
	)



	esp32s2tft.set_text_color(
		0x00FF00 if arcs < 1.0 else 0xFF0000 if logging else 0xFF00FF, status
	)

	esp32s2tft.set_text_color(
		0xFF0000 if esp32s2tft.peripherals.button else 0x606060, info_label
	)
	#esp32s2tft.peripherals.led = esp32s2tft.peripherals.button
	#if esp32s2tft.peripherals.button:
	#	esp32s2tft.peripherals.neopixel[0] = colorwheel(random.randint(0, 255))

	esp32s2tft.display.refresh ()

	if DipSW['3'].value == False: ## ref signal > 100mV, arcs < 20
        	# Firecapture PlugIn Compatible
                print ('A0: {:4.2f}'.format(Voltage(ref))) # Intensity Value (Volts)
#                print ('A0: {:4.2f}'.format(arcs_median-2)) # Median last 17 Seeing readings [testing]
                print ('A1: {:4.2f}'.format(arcs)) # Normalized RMS / Variation Value / Seeing
#                print ('C2: {:4.2f}'.format(sum(arcs_hist[-10:])/10)) # Average Seeing last 10 readings
#                print ('M1: {:4.2f}'.format(arcs_median)) # Median last 17 Seeing readings
        else:
                print (status_reading, long_reading)
                        
	

        # WiFi + MQTT?
        if WiFi and mqtt_client_connected: ## ref signal > 100mV, arcs < 20
		try:
			esp32s2tft.peripherals.led = True
			print("MQTT publishing...")
			# Poll the message queue
			#mqtt_client.loop()
			# Send a new message
                        #if s%3: # throttle rate
                        if 1: # no throttle
			        #mqtt_client.publish(sssm_time_feed, nowns/1e9)
			        mqtt_client.publish(sssm_ref_feed, Voltage(ref))
			        mqtt_client.publish(sssm_arcs_feed, arcs)
			if s%60 == 0:
				mqtt_client.publish(sssm_bat_feed, bm_cell_percent)
			esp32s2tft.peripherals.led = False
			info_last = "MQTT transmitting"
		except (ValueError, RuntimeError) as e:
			esp32s2tft.peripherals.led = False
			print("MQTT failed, retrying. WiFi reset/reconnect attempt. E:", e)
			info_last = "WiFi reset attempt"
			try:
			        print('*** WiFi Reset/Reconnect attempt')
			        wifi.reset()
			        wifi.connect()
			        mqtt_client.reconnect()
			        print('*** WiFi Reset/Reconnect attempt completed')
			except (ValueError, RuntimeError) as e:
				print("WiFi reset failed, retrying next loop. E:", e)
        else:
		info_last = "No MQTT."
		esp32s2tft.peripherals.led = False
                
	if arcs < PhotoOKArcs:
                info_last = 'Photo OK * '+info_last
		esp32s2tft.peripherals.led = True
		PinPhotoOK.value = True
	else:
		PinPhotoOK.value = False

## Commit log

2023-01-13 Circuit Python 8 Libs required
2023-01-15 Add files via upload
    Cleanup and new revisions uploaded
    [Feather TFT.step, SSSM-Feather-ESP32-S3-TFT-box-A.stl, SSSM-Feather-ESP32-S3-TFT-box-A.stp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]
2023-01-15 Add files via upload
    Added and updated
    [SSSM-Feather-ESP32-S3-TFT-box-Ap3mm.stl, SSSM-Feather-ESP32-S3-TFT-box-Ap6mm.stl]
2023-01-15 Add files via upload
    updates
    [SSSM-Feather-ESP32-S3-TFT-box.stp]
2023-02-17 added clamp
    added clamp 154.4mm
2023-02-25 Add files via upload
    With Bracket for 155mm tube
    [SSSM-Feather-ESP32-S3-TFT-box-bracket-156.stl, SSSM-Feather-ESP32-S3-TFT-box-bracket-157-new.stl, SSSM-Feather-ESP32-S3-TFT-box-bracket-158.stl]
